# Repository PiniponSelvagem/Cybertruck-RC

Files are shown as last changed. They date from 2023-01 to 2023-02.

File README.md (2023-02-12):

# Cybertruck-RC
Cybertruck bluetooth radio controlled, project for the class DI3D (Design and 3d Printing) at ISEL, Instituto Superior de Engenharia de Lisboa.

This project contains the 3D model, the micro controller source code and the Android application source code.

## Features
It dances!
- Tesla Model X light show: https://www.youtube.com/watch?v=nrMW4mIjMkw
- Knight Rider light show: https://www.youtube.com/watch?v=KawXGOTbI-Q

Light modes:
- Blinkers, left, right and hazards
- Low beam
- Hight beam
- Brake

Oh, almost forgot... it drives.
- Foward / Backward
- Precision turning
- demo: https://www.youtube.com/watch?v=zXTYGtbgDoM

<br>

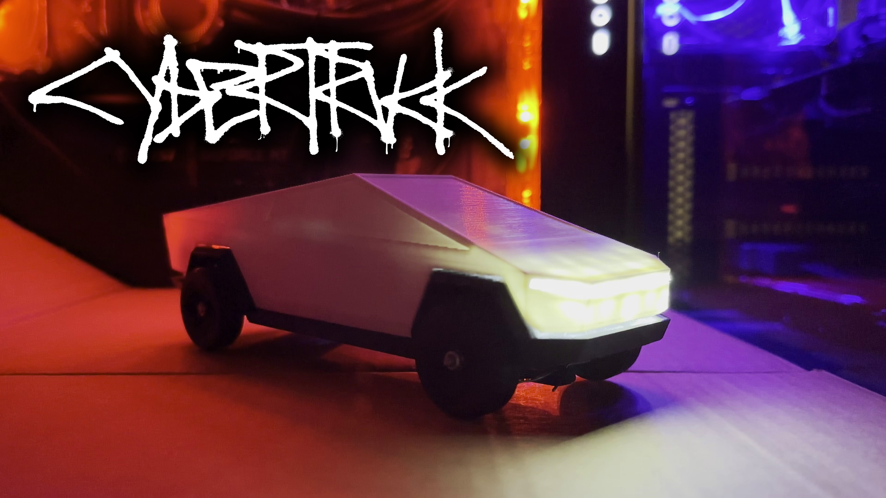
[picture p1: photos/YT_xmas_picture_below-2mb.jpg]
Cybertruck RC


# 3D model
Created using OpenScad 2021.01, based of Tesla Cybertruck.<br>
The main file is **cybertruck.scad**, located at **3d_model** folder.<br>
It used PolyGear by Dario Pellegrini, https://github.com/dpellegr/PolyGear, for the back servo / motor to drive both wheels at same time.

# Microcontroller
The Cybertruck is controlled by a TTGO T-Beam v1.1 via Bluetooth.<br>
The TTGO T-Beam is running micropython, that can be found at https://github.com/nunomcruz/pycom-micropython-sigfox, ported by Nuno Cruz.
It is able to control 10 LEDs independently, each LED has its own dedicated PIN, and can control 2 servos.

Known bugs:
- servos drain battery when powered off, maybe a configuration within AXP192 can fix?

---
## Servos
The servos used are from Turnigy, TGY-R5180MG since they were the ones i had around. They are 180 degree servos, but since they dont have a stopper, one of them could be used has a motor without any hardware modification. The trick was the give him 2 specific invalid duty cycles, to trick him to run around. Very small duty cycle makes the servor spin around forward, while larger duty cycle makes it go backwards. Note that the backward movement gets a bit messed up (the servo jigles a bit at each 360 degree rotation), but with a duty cycle large enough it will run slow making it almost unnoticeable.

A continuous rotation servo can be used, but some adjustments will be required, such as:
- edit the file **servos.py** located at **/microcontroller/python/cybertruck**, by making the necessary adjustments to support it at the class **Motor**

PINs used:
- Pin 25 for direction servo
- Pin 2 for motor servo

---
## LEDs
5 white, 5 red with 220ohm resistors each.<br>
Due to board PINs limitation, the UART and I2C cannot be used while the LEDs are configured... but they actually can with a small work around.<br>
UART can be used to get a USB terminal, by during boot checking if the user is pressing the middle button of the TTGO. This will enter in a "debug" mode, by not configuring the UART PINs as output for the LEDs. It also looks cool while transfering data.<br>
I2C is used to keep track of the battery level, every minute the 2 LEDs at PINs 21 and 22 get their configuration reset to I2C, the percentage is calculated and then the PINs are set back to output. Barelly noticable while normal operation of the LEDs, unless you know exactly what to look for.

Pins used: (counting while looking from the front, and from the passenger side to the driver side)<br>
Head lights:
- Pin 01 - Headlight left
- Pin 03 - Headlight left middle
- Pin 23 - Headlight middle
- Pin 04 - Headlight right middle
- Pin 00 - Headlight right

Tail lights:
- Pin 15 - Taillight left
- Pin 14 - Taillight left middle
- Pin 13 - Taillight middle
- Pin 22 - Taillight right middle
- Pin 21 - Taillight right

# Android Application
Android application targeted for Android 5.1 or above.

**Currently the TTGO Bluetooth mac address is hardcoded, this should get fixed in a later version with a nearby bluetooth device list.**

Full control of the Cybertruck, with the added spirit of the cyber / neon colored app theme.

Known bugs:
- Hardcodded TTGO bluetooth mac address.
- If the hazards button is the first on to be pressed, sometimes it can lock other dashboard buttons interactions until app restart.
- Light configuration can mess up sometimes. Rare occurance, and until fix found a simple app restart can fix it.
- When dancing, if around 5 or more light configurations of 100ms delay get send to the TTGO, the microcontroller buffers can get full and the light configuration will be skipped. This is down to the developer to be carefull when creating dances. It is not recommented to send light configurations with less than 100ms delay, since they can / will be lost.

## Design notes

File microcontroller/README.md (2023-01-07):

# Cybertruck-RC
# Microcontroller
The Cybertruck is controlled by a TTGO T-Beam v1.1 via Bluetooth.<br>
The TTGO T-Beam is running micropython, that can be found at https://github.com/nunomcruz/pycom-micropython-sigfox, ported by Nuno Cruz.
It is able to control 10 LEDs independently, each LED has its own dedicated PIN, as well has control 2 servos.

---
## Servos
The servos used are from Turnigy, TGY-R5180MG since they were the ones i had around. They are 180 degree servos, but since they dont have a stopped, one of them could be used has a motor without any hardware intervention. The trick was the give him 2 specific invalid duty cycles, to trick him to run around. Very small duty cycle makes the servor spin around forward, while larger duty cycle makes it go backwards. Note that the backward movement gets a bit messed up (the servo jigles a bit at each 360 degree rotation), but with a duty cycle large enough it will run slow making it almost unnoticeable.

A continuous rotation servo can be used, but some adjustments will be required, such as:
- edit the file **servos.py** located at **/microcontroller/python/cybertruck**, by making the necessary adjustments to support it at the class **Motor**

PINs used:
- Pin 25 for direction servo
- Pin 2 for motor servo

---
## LEDs
5 white, 5 red with 220ohm resistors each.<br>
Due to board PINs limitation, the UART and I2C cannot be used while the LEDs are configured... but they actually can with a small work around.<br>
UART can be used to get a USB terminal, by during boot checking if the user is pressing the middle button of the TTGO and not letting those 2 Pins be configured as output for the LEDs. Also looks cool while transfering data.<br>
I2C is used to keep track of the battery level, every minute the 2 LEDs at PINs 21 and 22 get their configuration reset to I2C, the percentage is calculated and then the PINs are set back to output. Barelly noticable while normal operation of the LEDs unless you know exactly what to look for.

Pins used: (counting while looking from the front, and from the passenger side to the driver side)
- Pin 1 - Headlight left
- Pin 3 - Headlight left middle
- Pin 23 - Headlight middle
- Pin 4 - Headlight right middle
- Pin 0 - Headlight right
<br>
<br>
- Pin 15 - Taillight left
- Pin 14 - Taillight left middle
- Pin 13 - Taillight middle
- Pin 22 - Taillight right middle
- Pin 21 - Taillight right

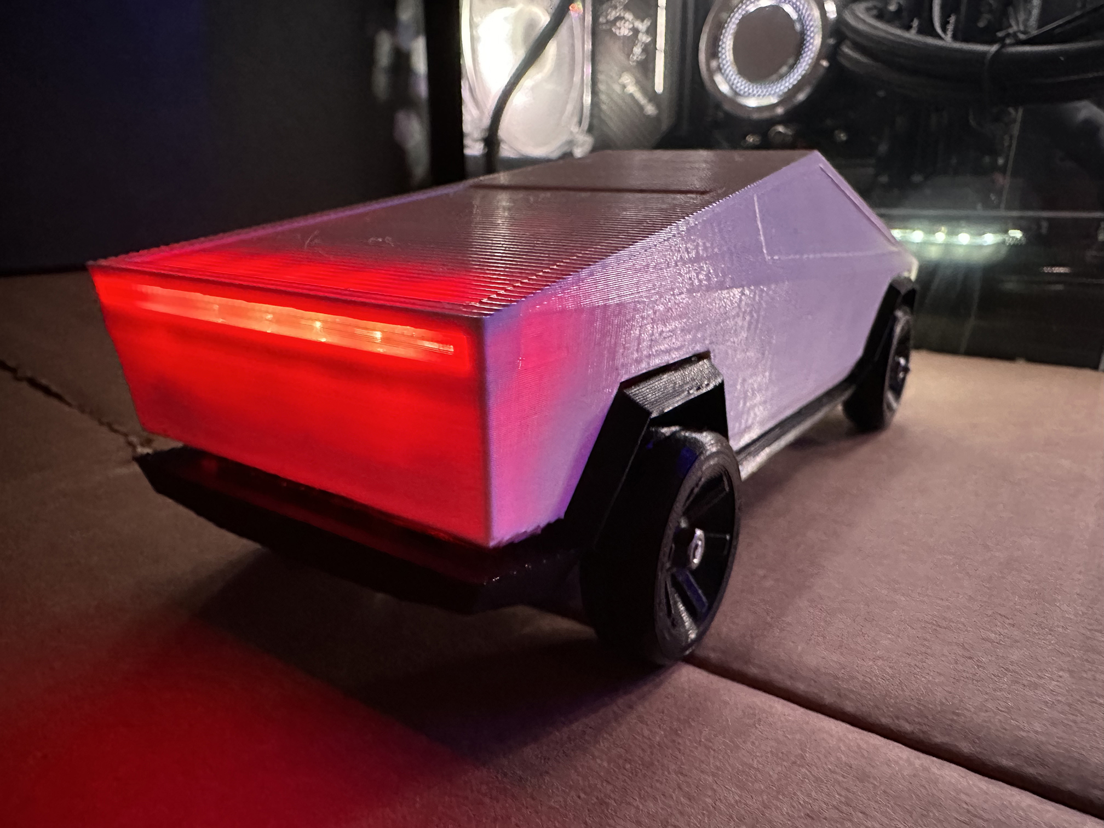
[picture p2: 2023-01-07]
photos/10_night_side_back__halfsize.jpg

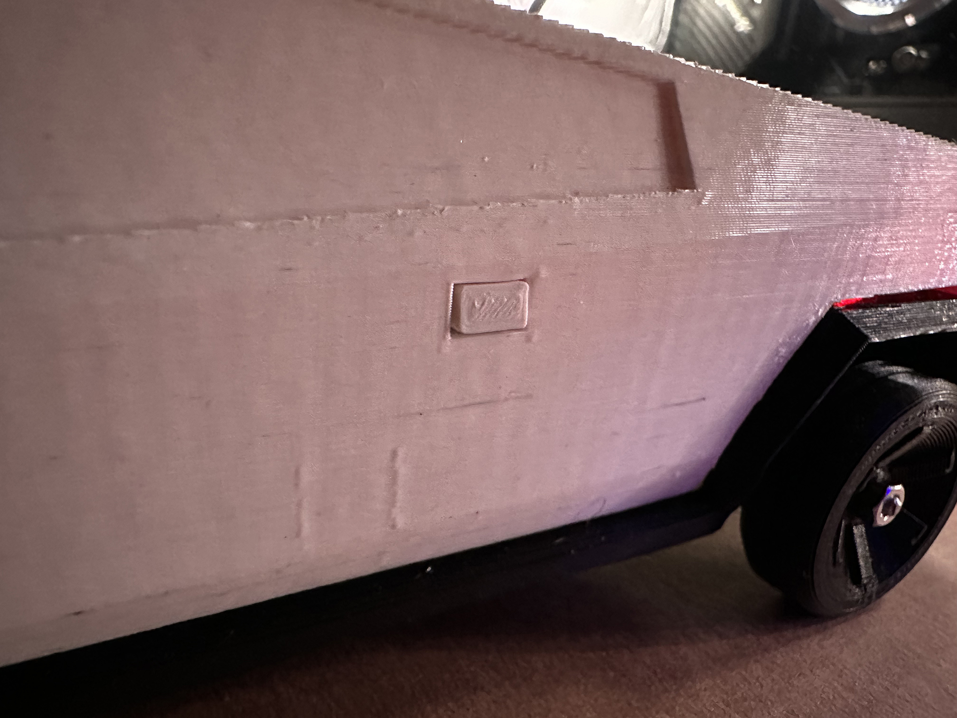
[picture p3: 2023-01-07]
photos/15_night_power_button__halfsize.jpg

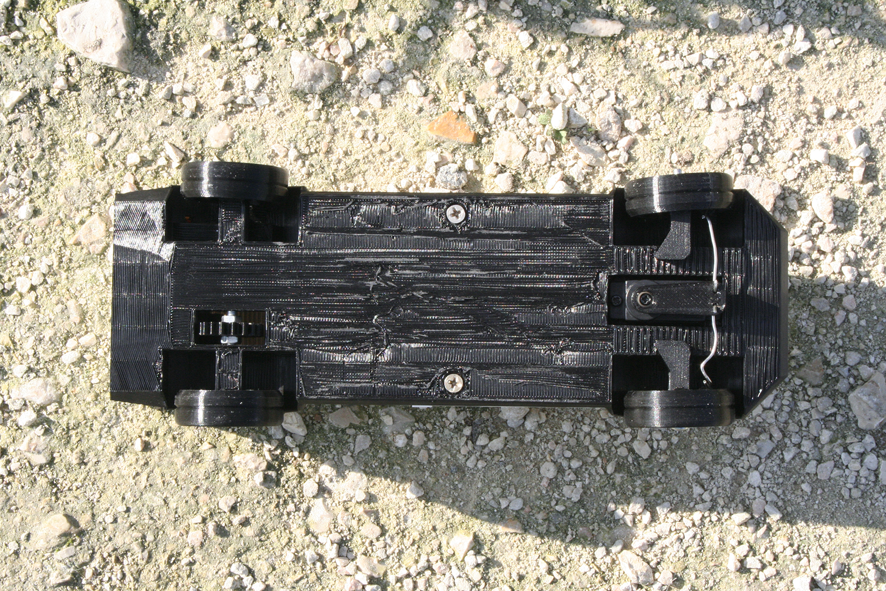
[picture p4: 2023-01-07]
photos/06_day_bottom__halfsize.jpg

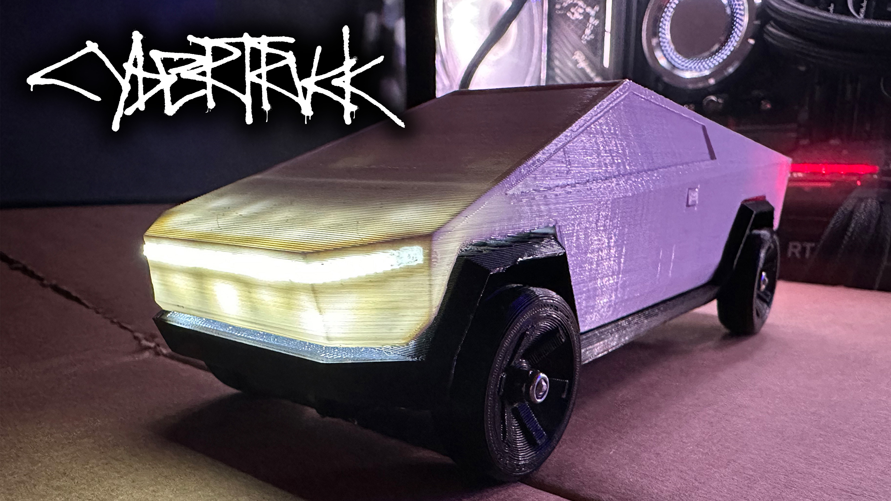
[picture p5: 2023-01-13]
photos/YT_kitt_picture_below-2mb.jpg

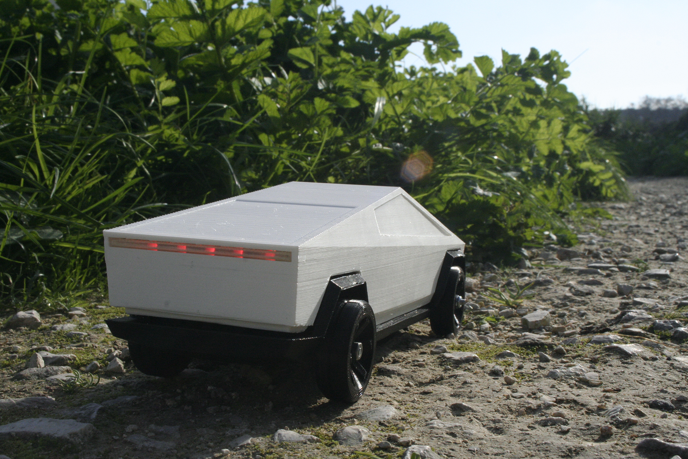
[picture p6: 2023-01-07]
photos/02_day_side_back__halfsize.jpg

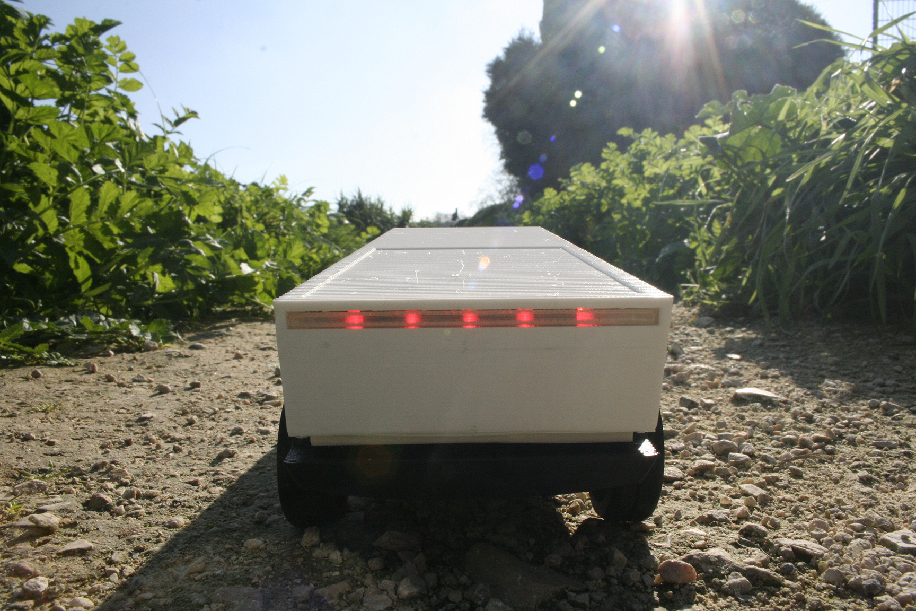
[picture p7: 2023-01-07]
photos/04_day_back__halfsize.jpg

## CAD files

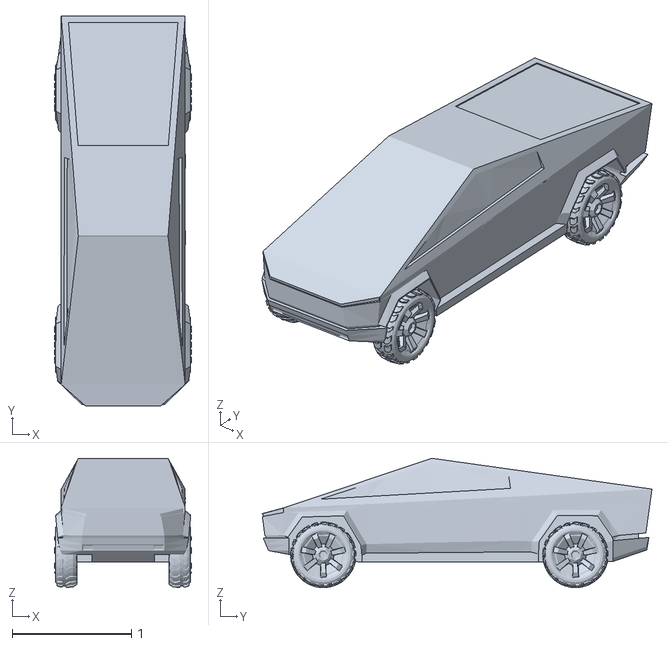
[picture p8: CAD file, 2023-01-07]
3d_model/3d-cybertruck.stl
1.15 x 3.28 x 1.09

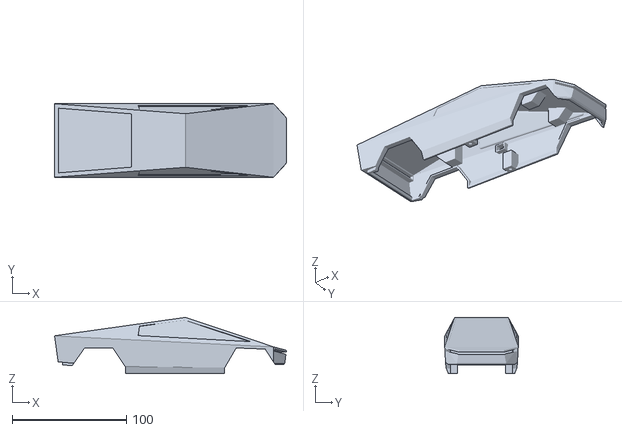
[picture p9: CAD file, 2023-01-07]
3d_model/exported/cybertruck_top_preview.stl
203.1 x 64.5 x 49.2

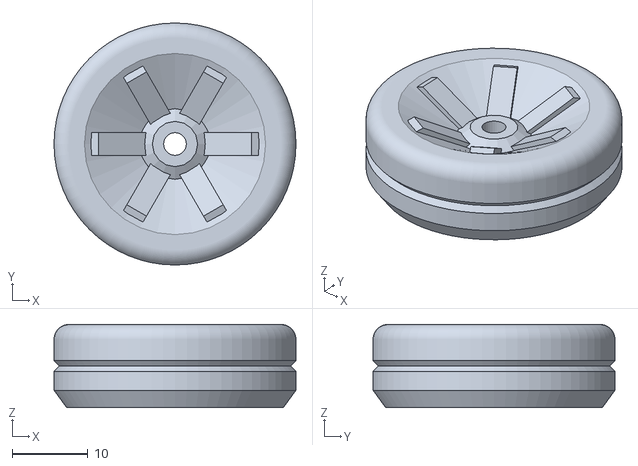
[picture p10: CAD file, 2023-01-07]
3d_model/exported/wheel_no_supports.stl
32.0 x 32.0 x 11.0

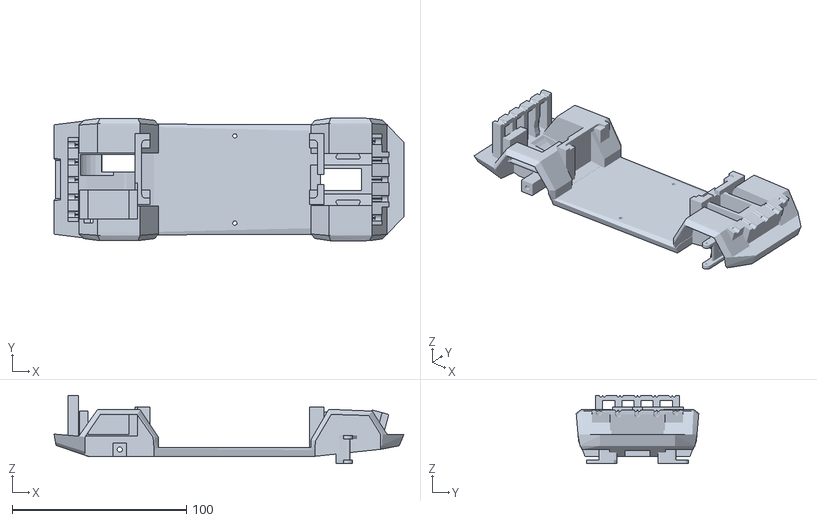
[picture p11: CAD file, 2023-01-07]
3d_model/exported/cybertruck_bottom_preview.stl
200.8 x 70.4 x 39.1

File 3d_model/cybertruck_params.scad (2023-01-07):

/**
* @file     cybertruck_params.scad
* @brief    Parameters for CyberTruck RC.
* @version  1.1
* @date     04 Dec 2022
* @author   PiniponSelvagem
*
* Copyright(C) 2022-2023, PiniponSelvagem
* All rights reserved.
*
***********************************************************************
* Software that is described here, is for illustrative purposes only
* which provides customers with programming information regarding the
* products. This software is supplied "AS IS" without any warranties.
**********************************************************************/

include <ttgo_t-beam_model.scad>

/**
* NOTE: If the array is related to wheels positions and/or similar,
* the array should be seen as the car going up this code, with its top
* going towards you.
*
* Example:
*   front of the car
*   [
*       value1, value2,
*       value3, value4
*   ]
*   back of the car
*
* Unless otherwise stated.
*/

/**
* NOTE: If the array is related to servo positions and/or similar,
* the array should be seen as the car going up this code, with its top
* going towards you.
*
* Example:
*   front of the car
*   [
*       value1,
*       value2
*   ]
*   back of the car
*
* Unless otherwise stated.
*/


/* MODE */
// WARNING: SET ALL PREVIEW TO false WHEN EXPORTING
PREVIEW_TOP = false;
PREVIEW_BOT = false;


/* TTGO T-BEAM v1.1 */
TTGO_POSITION = [-3, 6, -3];
TTGO_ROTATION = [0, 0, 180];

TTGO_WALL_THICKNESS = [8, 8];
TTGO_MIDDLE_WALL_CUT_SIZE = 91.6;

TTGO_BOARD_STEP_SIZE_MULT = 4;    // at top part of cybertruck
TTGO_BOARD_THICKNESS = 1.8;

TTGO_STEP_SIZE_UP   = 20;
TTGO_STEP_SIZE_DOWN = 22;


/* TTGO POWER BUTTON */
POWER_BTN_POSITION = [TTGO_POSITION.x, 0, TTGO_POSITION.z] + [0, 6, 0];
POWER_BTN_HOUSING = TTGO_BTN_SIZE + [4, 2, 4];
POWER_BTN_HOUSING_MARGIN = 1.8;
POWER_BTN_MARGIN = 2.4;


/* SERVOS */
SERVO_POSITION = [ [61,   0, -20], [-72.4, -6, -10] ];
SERVO_ROTATION = [ [ 0, 180, 180], [-90,    0,   0] ];
SERVO_CABLE_CUT_POSITION_OFFSET = [ [-12, 0, 18], [-12, -16, 1] ];
SERVO_CABLE_CUT_SIZE = [ [6, 6, 6], [6, 6, 8] ];


/* SCREW TOOL CUT */
STOOL_POSITION = [-58.4, -5, -9.9];
STOOL_SIZE = 50;
STOOL_RADIUS = 2;


/* WHEELS */
WHEEL_POSITION = [
    [ 65, 29.5, -25], [ 65, -29.5, -25],
    [-66, 29.5, -25], [-66, -29.5, -25]
];



/* GEARS */
GEAR_TEETH = [21, 17];
GEAR_WIDTH = [5, 4];
GEAR_AXLE_CENTER_RADIUS = 1.5;  // TODO: maybe place WHEEL_AXLE_... here
GEAR_AXLE_CENTER_FACES  = 16;
GEAR_ATTACH_OFFSET = 2.4;


/* SCREWS */
SCREW_BODY_TUNNEL_SIZE = 14;
SCREW_BODY_TUNNEL_RADIUS = 1.4;
SCREW_BODY_TUNNEL_FACES = 5;

SCREW_HEAD_SIZE = 3.2;
SCREW_HEAD_TUNNEL_SIZE = 8;
SCREW_HEAD_RADIUS_AT_BODY = 1.4;
SCREW_HEAD_RADIUS = 4.0;
SCREW_HEAD_FACES = 32;

/* front and back
SCREW_POSITION      = [ [89, 0, -25   ], [-93, 0, -25  ] ];
SCREW_FILL_POSITION = [ [90, 0, -11.9 ], [-93, 0, -11.4] ];
SCREW_FILL_SIZE     = [ [ 8, 6,   8.8 ], [  5, 6,   9] ];
*/
// TODO: remove hardcoded "remove outside excess" in "... screw fill"
SCREW_POSITION      = [ [0, 25, -29   ], [0, -25, -29  ] ];
SCREW_FILL_POSITION = [ [0, 26, -16.9 ], [0, -26, -16.9] ];
SCREW_FILL_SIZE     = [ [8, 10,  14   ], [8,  10,  14  ] ];


/* DEBUG */
// set 0 or false to disable, 1 or true to enable
// except for DEBUG_WHEEL_ANGLE that uses int value as degrees
DEBUG_CYBERTRUCK   = 0;
DEBUG_TTGO         = 0;
DEBUG_SERVO        = [0, 0];
DEBUG_SERVO_CENTER = [0, 0];
DEBUG_WHEELS       = [0, 0, 0, 0];
DEBUG_WHEEL_TURN   = [0, 0];
DEBUG_WHEEL_ANGLE  = [0, 0];    // NOT 100% accurary representation
DEBUG_AXLE_REAR    = 0;
DEBUG_GEARS        = 0;

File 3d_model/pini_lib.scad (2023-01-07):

/**
* @file     pini_lib.scad
* @brief    Small library developed to be used with OpenScad.
* @version  1.2
* @date     30 Nov 2022
* @author   PiniponSelvagem
*
* Copyright(C) 2022-2023, PiniponSelvagem
* All rights reserved.
*
***********************************************************************
* Software that is described here, is for illustrative purposes only
* which provides customers with programming information regarding the
* products. This software is supplied "AS IS" without any warranties.
**********************************************************************/

/**
 * Easy minkowsky that keeps the original size of a cube.
 * @param cubeSize Size of the main cube.
 * @param radius Radius of the corners.
 * @param nFaces Number of faces for the corners.
 * @param isSphere Should be a sphere, if not then use a cylinder. (Optional)
 * @param rotation Rotation of the secondary object. Only used if isSphere==true. (Optional)
 */


FIX_Z_FIGHTING = 0.01;


/**
 * Easy minkowsky that keeps the original size of a cube.
 * @param cubeSize Size of the cube.
 * @param radius Radius of the corners.
 * @param nFaces Number of faces for the corners. (Optional)
 * @param isSphere True uses a sphere, false uses a cylinder.
 */
module minkowskiEasy_cube(cubeSize, radius, nFaces=64, isSphere=true, rotation=[0,0,0]) {
    if (isSphere) {
        minkowski() {
            //Minkowski size fix
            matx=cubeSize.x - radius*2; 
            maty=cubeSize.y - radius*2;
            matz=cubeSize.z - radius*2;
            
            // body with minkowski adjustments
            cube([matx,maty,matz], center=true);

            // corners
            sphere(r=radius, $fn=nFaces);
        }
    }
    else {
        rotate(rotation) {
            minkowski() {
                //Minkowski size fix
                matx=cubeSize.x - radius*2; 
                maty=cubeSize.y - radius*2;
                matz=cubeSize.z/2;
                
                // body with minkowski adjustments
                cube([matx,maty,matz], center=true);

                // corners
                cylinder(h=matz, r=radius, $fn=nFaces, center=true);
            }
        }
    }
}

/**
 * Easy minkowsky that keeps the original size of a cylinder.
 * @param cyHeight Size of the main cylinder.
 * @param cyRadius Radius of the main cylinder.
 * @param radiusCorner Radius of the corners.
 * @param nFaces Number of faces for the corners. (Optional)
 */
module minkowskiEasy_cylinder(cyHeight, cyRadius, radiusCorner, nFaces=64) {
    minkowski() {
        //Minkowski size fix
        radius=cyRadius - radiusCorner; 
        height=cyHeight - radiusCorner*2;
        
        // body with minkowski adjustments
        cylinder(h=height, r1=radius, r2=radius, $fn=nFaces, center=true);

        // corners
        sphere(r=radiusCorner, $fn=nFaces);
    }
}

/**
 * Isosceles triangle, taken from: Thejollymreaper youtube channel.
 * Video link: https://www.youtube.com/watch?v=QcQJvNeJat0
 * @param side Side size.
 * @param tall Triangle tall height at the center.
 * @param cornerRadius Corner radius to create rounded corner.
 * @param cornerFaces Number for corner faces.
 * @param height Thickness of the triangle.
 * @param center Center objects vertically.
 */
module triangle(side, tall, cornerRadius, cornerFaces, thickness, center=false) {
    translate([0, cornerRadius, 0])
    hull() {
        translate([side/2 - cornerRadius, 0, 0])
        cylinder(h=thickness, r=cornerRadius, $fn=cornerFaces, center=center);

        translate([-side/2 + cornerRadius, 0, 0])
        cylinder(h=thickness, r=cornerRadius, $fn=cornerFaces, center=center);

        translate([0, tall-cornerRadius*2, 0])
        cylinder(h=thickness, r=cornerRadius, $fn=cornerFaces, center=center);
    }
}


/**
 * Create a screw hole at position.
 * @param position Origin is at the center of the lower face of the screw, with the screw pointing up.
 * @param screwBodyTunnel_size Lenght of the tunnel for the screw body.
 * @param screwBodyTunnel_radius Radius of the tunnel screw body.
 * @param screwBodyTunnel_faces Number of faces for the tunnel screw body.
 * @param screwHead_size Lenght of the in between portion, where the head will sit.
 * @param screwHeadTunnel_size Leght of the tunnel at the head side of the screw.
 * @param screwHead_radiusAtBody Radius of the screw at body.
 * @param screwHead_radius Radius of the screw at head.
 * @param screwHead_faces Number of faces for the tunnel head screw.
 */
module screwHole(
    position,
    screwBodyTunnel_size, screwBodyTunnel_radius, screwBodyTunnel_faces,
    screwHead_size, screwHeadTunnel_size, screwHead_radiusAtBody, screwHead_radius, screwHead_faces
) {
    translate(position) {
        union() {
            // screw tunnel
            translate([0, 0, screwHead_size])
            rotate([0, 0, 45])
            cylinder(h=screwBodyTunnel_size, r=screwBodyTunnel_radius, $fn=screwBodyTunnel_faces);

            // head
            translate([0, 0, FIX_Z_FIGHTING])
            cylinder(h=screwHead_size, r1=screwHead_radius, r2=screwHead_radiusAtBody, $fn=screwHead_faces);

            // head tunnel
            translate([0, 0, FIX_Z_FIGHTING*2])
            rotate([0, 180, 0])
            cylinder(h=screwHeadTunnel_size, r=screwHead_radius, $fn=screwHead_faces);
        }
    }
}

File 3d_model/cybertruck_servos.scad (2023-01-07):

/**
* @file     cybertruck_servos.scad
* @brief    CyberTruck RC servos
* @version  1.0
* @date     25 Nov 2022
* @author   PiniponSelvagem
*
* Copyright(C) 2022-2023, PiniponSelvagem
* All rights reserved.
*
***********************************************************************
* Software that is described here, is for illustrative purposes only
* which provides customers with programming information regarding the
* products. This software is supplied "AS IS" without any warranties.
**********************************************************************/

_SERVO_FIX_Z_FIGHT = 0.01;

/* SERVO TURNIGY: TGY-R5180MG */
SERVO = [23.4, 12.6, 21.6];
SERVO_SCREW_PLANE = [32.6, 12.4, 1.8];
SERVO_SCREW_PLANE_HEIGHT = 16.6;    // at bottom of the plane
SERVO_ROTOR_HEIGHT = 4.4;
SERVO_HEAD_TOTAL_THICKNESS = 4.4;


/* SERVO ATTACH */
SERVO_ATTACH_BORDER = 1;
SERVO_ATTACH_HEIGHT = 4;              // total attach height
SERVO_ATTACH_SIMPLE_FACES = [12, 8];  // [bigger side, smaller side]
SERVO_ATTACH_ROUND_FACES = 16;
SERVO_ATTACH_SIMPLE_HOLDER_POSITION = [8, 2.6, 0];
SERVO_ATTACH_SIMPLE_HOLDER_ROTATION = [0, 45, 87];
SERVO_ATTACH_SIMPLE_HOLDER_SIZE = [1, 6, 1];

SERVO_HEAD_SIMPLE_TRANSLATION = 16;
SERVO_HEAD_SIMPLE_TRANSLATION_FILLED = [20, 2];   // translation/distance between the 2 cylinders from their respective center
SERVO_HEAD_SIMPLE_THICKNESS   = 1;         // thickness of the head piece plane
SERVO_HEAD_SIMPLE_RADIUS      = [3, 2];    // [bigger side, smaller side]
SERVO_HEAD_ROUND_RADIUS = 9.2;

SERVO_SCREW_RADIUS_SIMPLE = 2.4;
SERVO_SCREW_RADIUS_ROUND  = 3;
SERVO_SCREW_HEIGHT = 2;


/* SERVO HOUSING */
SERVO_HOUSING = [SERVO.x + 10, SERVO.y + 2, SERVO_SCREW_PLANE_HEIGHT];
SERVO_HOUSING_SCREW_OFFSET = 14;
SERVO_HOUSING_SCREW_HEIGHT = 10;
SERVO_HOUSING_SCREW_RADIUS = 1;
SERVO_HOUSING_SCREW_FACES  = 4;


/**
 * Servo head piece plane.
 * @param h Thickness of the plane.
 */
module _servoHead_simple(h=SERVO_HEAD_SIMPLE_THICKNESS) {
    hull() {
        cylinder(h=h, r=SERVO_HEAD_SIMPLE_RADIUS.x, $fn=SERVO_ATTACH_BORDER+SERVO_ATTACH_SIMPLE_FACES.x);
        
        translate([SERVO_HEAD_SIMPLE_TRANSLATION, 0, 0])
        cylinder(h=h, r=SERVO_HEAD_SIMPLE_RADIUS.y, $fn=SERVO_ATTACH_BORDER+SERVO_ATTACH_SIMPLE_FACES.y);
    }
}

/**
 * Servo head round piece plane.
 * @param h Thickness of the plane.
 */
module _servoHead_round(h=SERVO_HEAD_SIMPLE_THICKNESS) {
    cylinder(h=h, r=SERVO_HEAD_ROUND_RADIUS, $fn=SERVO_ATTACH_ROUND_FACES);
}

/**
 * Servo screw hole.
 * @param xOffset Offset in the X axis.
 */
module _servoHousingScrew(xOffset) {
    translate([SERVO_HOUSING.x/2 + xOffset, SERVO_HOUSING.y/2 + 0, SERVO_SCREW_PLANE_HEIGHT - SERVO_HOUSING_SCREW_HEIGHT +_SERVO_FIX_Z_FIGHT])
    cylinder(h=SERVO_HOUSING_SCREW_HEIGHT, r1=SERVO_HOUSING_SCREW_RADIUS, r2=SERVO_HOUSING_SCREW_RADIUS, $fn=SERVO_HOUSING_SCREW_FACES);
}

/**
 * Debug servo visualization.
 * @param rotation Rotation in degrees.
 * @param alpha Alpha channel for the debug object.
 * @param type type of the head: 0->simple, 1->round
 */
module servoDebug(rotation=0, alpha=1, type=0, showCenter=false) {
    translate([-SERVO.x/2, -SERVO.y/2, -SERVO_SCREW_PLANE_HEIGHT]) {
        color("grey", alpha=alpha)
        cube(SERVO, center=false);

        color("grey", alpha=alpha)
        translate([-(SERVO_SCREW_PLANE.x/2 - SERVO.x/2), 0, SERVO_SCREW_PLANE_HEIGHT])
        cube(SERVO_SCREW_PLANE, center=false);

        color("grey", alpha=alpha)
        translate([SERVO.y/2, SERVO.y/2, SERVO.z])
        cylinder(h=SERVO_ROTOR_HEIGHT, r1=SERVO.y/2, r2=SERVO.y/2, center=false);

        color("white", alpha=alpha)
        translate([SERVO.y/2, SERVO.y/2, SERVO.z+SERVO_ROTOR_HEIGHT])
        rotate([0, 0, rotation])
        if (type == 0) {
            _servoHead_simple(SERVO_HEAD_TOTAL_THICKNESS);
        }
        else if (type == 1) {
            _servoHead_round(SERVO_HEAD_TOTAL_THICKNESS);
        }

        if (showCenter) {
            color("red", alpha=alpha)
            translate([SERVO.y/2, SERVO.y/2, SERVO.z+SERVO_ROTOR_HEIGHT])
            cylinder(h=16, r=1, $fn=16, center=false);
        }
    }
}

/**
 * Center children at servo rotation point.
 */
module servoRotationCenterPosition() {
    translate([-SERVO.x/2, -SERVO.y/2, -SERVO_SCREW_PLANE_HEIGHT])
    translate([SERVO.y/2, SERVO.y/2, SERVO.z+SERVO_ROTOR_HEIGHT])
    children();
}

/**
 * Flip servo attach, with the insert hole up.
 */
module servoAttach_flip() {
    translate([0, 0, SERVO_ATTACH_HEIGHT])
    rotate([0, 180, 0])
    children();
}

/**
 * Servo head attach filled.
 */
module servoAttach_simple_filled() {
    hull() {
        cylinder(h=SERVO_ATTACH_HEIGHT, r=SERVO_ATTACH_BORDER+SERVO_HEAD_SIMPLE_RADIUS.x, $fn=SERVO_ATTACH_SIMPLE_FACES.x);
        
        translate([SERVO_HEAD_SIMPLE_TRANSLATION_FILLED.x, SERVO_HEAD_SIMPLE_TRANSLATION_FILLED.y, 0])
        cylinder(h=SERVO_ATTACH_HEIGHT, r=SERVO_ATTACH_BORDER+SERVO_HEAD_SIMPLE_RADIUS.y, $fn=SERVO_ATTACH_SIMPLE_FACES.y);

        translate([SERVO_HEAD_SIMPLE_TRANSLATION_FILLED.x, -SERVO_HEAD_SIMPLE_TRANSLATION_FILLED.y, 0])
        cylinder(h=SERVO_ATTACH_HEIGHT, r=SERVO_ATTACH_BORDER+SERVO_HEAD_SIMPLE_RADIUS.y, $fn=SERVO_ATTACH_SIMPLE_FACES.y);
    }

    /*
    hull() {
        cylinder(h=SERVO_ATTACH_HEIGHT, r=SERVO_ATTACH_BORDER+SERVO_HEAD_SIMPLE_RADIUS.x, $fn=SERVO_ATTACH_SIMPLE_FACES.x);
        
        translate([SERVO_HEAD_SIMPLE_TRANSLATION, 0, 0])
        cylinder(h=SERVO_ATTACH_HEIGHT, r=SERVO_ATTACH_BORDER+SERVO_HEAD_SIMPLE_RADIUS.y, $fn=SERVO_ATTACH_SIMPLE_FACES.y);
    }
    */
}

/**
 * Hole for wire to control surfaces.
 */
module servoWireHole(zSizeOffset=0) {
    translate([0, 0, -_SERVO_FIX_Z_FIGHT])
    cylinder(h=SERVO_ATTACH_HEIGHT+_SERVO_FIX_Z_FIGHT*2+zSizeOffset, r=0.8, $fn=SERVO_ATTACH_SIMPLE_FACES.y);
}

/**
 * Servo head attach filled.
 */
module servoAttach_round_filled() {
    cylinder(h=SERVO_ATTACH_HEIGHT, r=SERVO_ATTACH_BORDER+SERVO_HEAD_ROUND_RADIUS, $fn=SERVO_ATTACH_ROUND_FACES);
}

module _servoAttach_simple_holder(isLeft) {
    if (isLeft) {
        intersection() {
            servoAttach_simple_filled();

            translate(SERVO_ATTACH_SIMPLE_HOLDER_POSITION)
            rotate(SERVO_ATTACH_SIMPLE_HOLDER_ROTATION)
            cube(SERVO_ATTACH_SIMPLE_HOLDER_SIZE, center=true);
        }
    }
    else {
        intersection() {
            servoAttach_simple_filled();

            translate([
                 SERVO_ATTACH_SIMPLE_HOLDER_POSITION.x,
                -SERVO_ATTACH_SIMPLE_HOLDER_POSITION.y,
                 SERVO_ATTACH_SIMPLE_HOLDER_POSITION.z
            ])
            rotate([
                 SERVO_ATTACH_SIMPLE_HOLDER_ROTATION.x,
                 SERVO_ATTACH_SIMPLE_HOLDER_ROTATION.y,
                -SERVO_ATTACH_SIMPLE_HOLDER_ROTATION.z
            ])
            cube(SERVO_ATTACH_SIMPLE_HOLDER_SIZE, center=true);
        }
    }
}

/**
 * Servo head attach, complete.
 */
module servoAttach_simple() {
    difference() {
        servoAttach_simple_filled();

        translate([0, 0, -_SERVO_FIX_Z_FIGHT])
        _servoHead_simple(SERVO_HEAD_SIMPLE_THICKNESS*2);

        translate([0, 0, SERVO_HEAD_SIMPLE_THICKNESS*2-_SERVO_FIX_Z_FIGHT*2])
        cylinder(h=SERVO_SCREW_HEIGHT+_SERVO_FIX_Z_FIGHT*4, r=SERVO_SCREW_RADIUS_SIMPLE, $fn=SERVO_ATTACH_BORDER+SERVO_ATTACH_SIMPLE_FACES.x);
    }

    _servoAttach_simple_holder(true);
    _servoAttach_simple_holder(false);
}

/**
 * Servo head attach, complete.
 */
module servoAttach_round() {
    difference() {
        servoAttach_round_filled();

        translate([0, 0, -_SERVO_FIX_Z_FIGHT])
        _servoHead_round(SERVO_HEAD_SIMPLE_THICKNESS*2);

        translate([0, 0, SERVO_HEAD_SIMPLE_THICKNESS*2-_SERVO_FIX_Z_FIGHT*2])
        cylinder(h=SERVO_SCREW_HEIGHT+_SERVO_FIX_Z_FIGHT*4, r=SERVO_SCREW_RADIUS_ROUND, $fn=SERVO_ATTACH_BORDER+SERVO_ATTACH_SIMPLE_FACES.x);
    }
}

/**
 * Servo body filled.
 */
module servoFill() {
    translate([-SERVO_HOUSING.x/2, -SERVO_HOUSING.y/2, -SERVO_SCREW_PLANE_HEIGHT])
    translate([SERVO_HOUSING.x/2-SERVO.x/2, SERVO_HOUSING.y/2-SERVO.y/2, -_SERVO_FIX_Z_FIGHT])
    cube(SERVO);
}

/**
 * Servo body housing, including screw holes.
 * @param doFill True to do basic cube, usefull to use for difference on other objects. False normal housing.
 * @param sizeOffset Adjust the housing dimensions, note that center must be done using translation to accommodate the offset if desired. Ignored if doFill is false.
 */
module servoHousing(doFill=false, sizeOffset=[0, 0, 0]) {
    translate([-SERVO_HOUSING.x/2, -SERVO_HOUSING.y/2, -SERVO_SCREW_PLANE_HEIGHT])
    if (doFill) {
        cube(SERVO_HOUSING + sizeOffset);
    }
    else {
        difference() {
            cube(SERVO_HOUSING);
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

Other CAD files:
3d_model/cybertruck_wheel.scad
3d_model/PolyGear/PolyGear.scad
3d_model/PolyGear/PolyGearBasics.scad
3d_model/PolyGear/PolyGearUtils.scad
3d_model/PolyGear/linspace.scad
3d_model/PolyGear/shortcuts.scad
3d_model/cybertruck.scad
3d_model/cybertruck_bottom.scad
3d_model/cybertruck_gear.scad
3d_model/cybertruck_lights.scad
3d_model/cybertruck_supports.scad
3d_model/cybertruck_top.scad
3d_model/cybertruck_ttgo.scad
3d_model/cybertruck_utils.scad
3d_model/model_cybertruck_bottom.scad
3d_model/model_cybertruck_top.scad
3d_model/ttgo_t-beam_model.scad

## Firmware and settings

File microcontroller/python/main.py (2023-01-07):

print("--- main.py ---")


from machine import Pin, I2C
from time import sleep_ms
import config

print("Button setup")
from lib.devices.button import Button
button = Button()

print("WiFi setup")
from lib.devices.wifi import WiFi
wifi = WiFi()
if wifi.connect(config.WIFI_SSID, config.WIFI_PASS):
    print("WiFi: "+config.WIFI_SSID)
else:
    print("WiFi: "+config.WIFI_SSID+", NOT FOUND")



def checkDebugUSB():
    """
    Since LEDs in PINs 1 and 3, are also used by UART for serial USB connection,
    During this stage, if the button is pressed, it will inform the lights to not
    use them.
    """
    enableTerminalUSB = False
    led = Pin('G4',  mode=Pin.OUT)
    for i in range(20):
        led.toggle()
        button.pullEvents()
        enableTerminalUSB = button.isPressed(0)
        if enableTerminalUSB == True:
            led(1)
            break
        sleep_ms(100)
    return enableTerminalUSB

usbDebug = checkDebugUSB()



#sleep_ms(30000)

from cybertruck.battery import Battery
battery = Battery()

from cybertruck.servos import Wheel, Motor
wheel = Wheel(20)
motor = Motor()

from cybertruck.lights import Lights
lights = Lights(usbDebug)


from cybertruck.controller import Controller
cybertruck = Controller(battery, wheel, motor, lights)
cybertruck.start()

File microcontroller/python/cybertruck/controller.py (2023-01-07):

from time import sleep
import _thread as Thread
from lib.devices.ble import BLE

from cybertruck.servos import Wheel
from cybertruck.servos import Motor
from cybertruck.lights import Lights
from cybertruck.battery import Battery

class Controller:
    def __init__(self, battery: Battery, wheel: Wheel, motor: Motor, lights: Lights):
        self.battery = battery
        self.wheel   = wheel
        self.motor   = motor
        self.lights  = lights

    def start(self):
        Thread.start_new_thread(self.bleAdvertiserTask, ())

    def controllerReset(self):
        self.wheel.setAngle(90)
        self.motor.setSpeed(0)

    def conn_cb (self, bt_o):
        events = bt_o.events()
        if  events & BLE.TG_CLIENT_CONNECTED:
            self.controllerReset()
            self.lights.effectConnected()
        elif events & BLE.TG_CLIENT_DISCONNECTED:
            self.controllerReset()
            self.lights.effectDisconnected()

    """
    def lights_cb_handler(self, chr, data):
        events, value = data
        if events & BLE.TG_CHAR_WRITE_EVENT:
            try:
                self.lights.setLH_1(value[0] & 0x01)
                self.lights.setLH_2(value[0] & 0x02)
                self.lights.setLH_3(value[0] & 0x04)
                self.lights.setLH_4(value[0] & 0x08)
                self.lights.setLH_5(value[0] & 0x10)
                
                self.lights.setLT_1(value[1] & 0x01)
                self.lights.setLT_2(value[1] & 0x02)
                self.lights.setLT_3(value[1] & 0x04)
                self.lights.setLT_4(value[1] & 0x08)
                self.lights.setLT_5(value[1] & 0x10)
            except:
                pass

    def control_cb_handler(self, chr, data):
        events, value = data
        if events & BLE.TG_CHAR_WRITE_EVENT:
            try:
                self.wheel.setAngle(value[0])
                self.motor.setSpeed(value[1])
            except:
                pass
    """

    def combined_cb_handler(self, chr, data):
        events, value = data
        if events & BLE.TG_CHAR_WRITE_EVENT:
            try:
                self.wheel.setAngle(value[0])
                self.motor.setSpeed(value[1])

                self.lights.setLH_1(value[2] & 0x01)
                self.lights.setLH_2(value[2] & 0x02)
                self.lights.setLH_3(value[2] & 0x04)
                self.lights.setLH_4(value[2] & 0x08)
                self.lights.setLH_5(value[2] & 0x10)
                
                self.lights.setLT_1(value[3] & 0x01)
                self.lights.setLT_2(value[3] & 0x02)
                self.lights.setLT_3(value[3] & 0x04)
                self.lights.setLT_4(value[3] & 0x08)
                self.lights.setLT_5(value[3] & 0x10)
            except:
                pass


    def bleAdvertiserTask(self):
        self.controllerReset()

        ble = BLE("Cybertruck")
        ble.createAdvertiser(
            "70696e696379626572747275636b0000",    #'pinicybertruck' and last 4 digits are free to use
            self.conn_cb,
            BLE.TG_CLIENT_CONNECTED | BLE.TG_CLIENT_DISCONNECTED
        )
        chrBattery = ble.createService(
            "70696e696379626572747275636b0100",
            "70696e696379626572747275636b0101",
            None,   # battery read
            BLE.TG_CHAR_READ_EVENT
        )
        ble.createService(
            "70696e696379626572747275636b0200",
            "70696e696379626572747275636b0201",
            self.combined_cb_handler,
            BLE.TG_CHAR_WRITE_EVENT
        )
        """
        ble.createService(
            "70696e696379626572747275636b0300",
            "70696e696379626572747275636b0301",
            self.lights_cb_handler,
            BLE.TG_CHAR_WRITE_EVENT
        )
        ble.createService(
            "70696e696379626572747275636b0400",
            "70696e696379626572747275636b0401",
            self.control_cb_handler,
            BLE.TG_CHAR_WRITE_EVENT
        )
        """

        while(True):
            value = self.battery.read()
            self.lights.reEnable_leds_at_i2c()
            try:
                chrBattery.value(value)
            except:
                pass # ignore exception: OSError: Error while sending BLE indication/notification
            sleep(60)

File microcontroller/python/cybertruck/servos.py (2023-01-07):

from lib.devices.servo import Servo

class Wheel:
    def __init__(self, angleRange):
        """
        angleRange  -> max angle range to turn to one of the sides, will mirror to the other side
        """
        self.servo = Servo('G25', 0)
        self.minAngle = 90 - angleRange
        self.maxAngle = 90 + angleRange
        self.servo.sync()

    def setAngle(self, angle):
        if angle < 90:
            angle = max(angle, self.minAngle)
        elif angle > 90:
            angle = min(angle, self.maxAngle)
        self.servo.setAngle(angle)



class Motor:
    def __init__(self):
        self.servo = Servo('G2', 1, min_duty=0.01, max_duty=0.99)
    
    def setSpeed(self, speed):
        if (speed == 0x01):
            self.servo.setDuty(0.01)
        elif (speed == 0xff):
            self.servo.setDuty(0.99)
        else:
            self.servo.setDuty(0)

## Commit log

2023-01-07 Added 3d_model, app_android and microcontroller source code.
    [3d-cybertruck.stl, cybertruck.scad, cybertruck_bottom.scad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]
2023-01-07 Added missing PolyGear library. Made Cybertruck STL generation easier.
    [PolyGear.scad, PolyGearBasics.scad, PolyGearUtils.scad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]
2023-01-07 Added missing back number plate cut to 3D model.
    [cybertruck.scad, cybertruck_bottom.scad, cybertruck_params.scad]
2023-01-07 Added preview generated STL models.
    [cybertruck_bottom_preview.stl, cybertruck_top_preview.stl, wheel_no_supports.stl]
2023-01-07 Added preview STL generation mode.
    [cybertruck.scad]
